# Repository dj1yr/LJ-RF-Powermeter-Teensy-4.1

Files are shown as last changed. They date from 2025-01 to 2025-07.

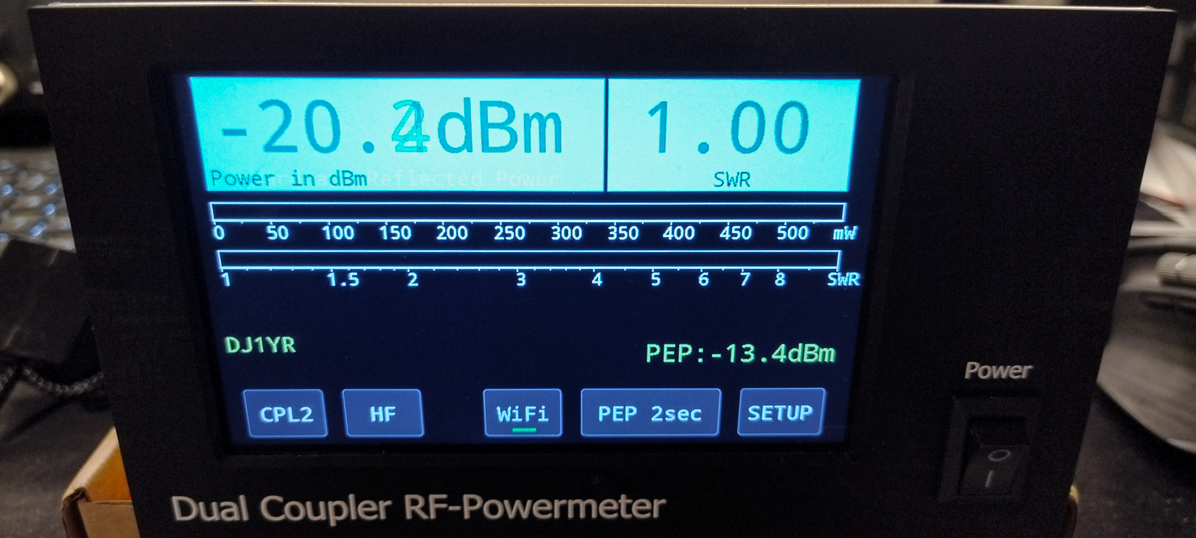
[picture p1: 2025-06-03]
IMG_20250603_050342225.jpg

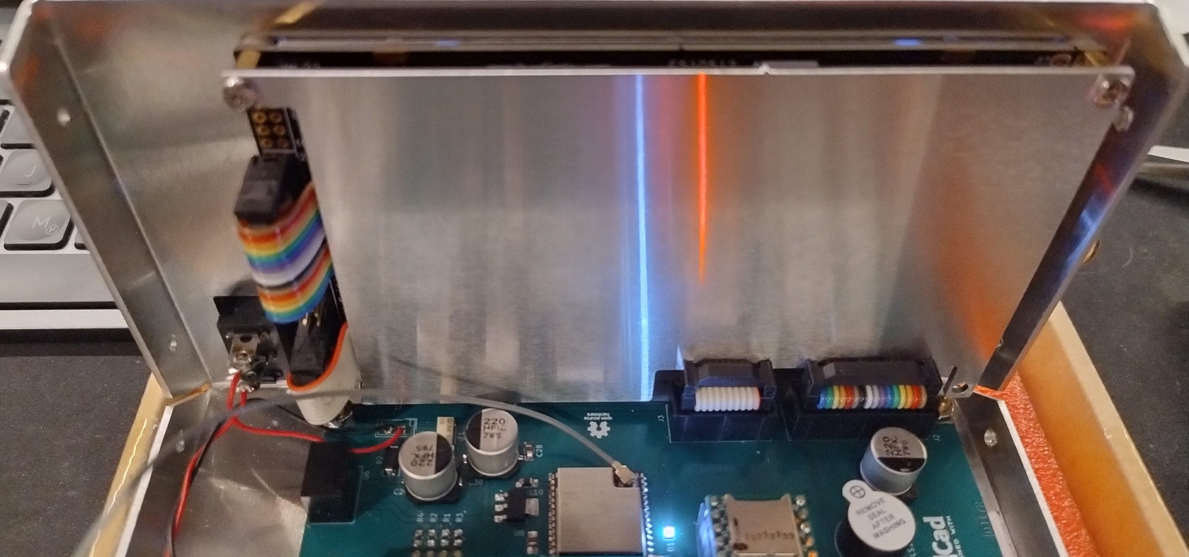
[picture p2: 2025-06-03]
IMG_20250603_050323348_HDR.jpg

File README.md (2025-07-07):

Here is a collection of files for the RF Powermeter with Teensy 4.0/4.1.
Since I could not find any source files for the PCB, I designed two boards based on Robert Entwistle (WA2T) and the really impressive software by Johan G. Holstein (PD0LEW).
The Rev3n is based on a main board on which different RF boards can be plugged to find the best solution for each application.

I try to create a complete folder with all files here, my board files are welcome to be used and improved.

The board was designed with Kicad and the enclosure parts are designed with Inventor.

73' René

**Revisions:**

REV3.6:

-Connection J2 pin14 to 3.3V(L13 + C3 must be populated for the new 7" display) 

-LAN and User I/O Header removed
-SMA connection added to User IO 6 if frequency measurement is added

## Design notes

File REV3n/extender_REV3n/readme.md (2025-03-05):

I have designed another RF extender board with HMC849 as RF switch, first measurements looked very good. The plan is to design an RF board up to 23cm, which then has 3 coupler inputs. Some adjustments have to be made to the software, so for the time being a version with two coupler inputs and AD8307.
The question has been asked why I am not using PE4259 as in the original design.
It is very difficult to get original working PE4259, I had ordered many from ebay, Ali etc, all were fakes.
Then I found the test boards with HMC 349/849, you can easily test them and make sure they work.
Since I have a hot air soldering station, it was very easy to take these tested ICs and place them on my board.
I also tried soldering them on with a soldering iron, which also worked, and I added a 2mm VIA to the ground plane under the HMC.

-In the REV3.6 the 74HC04 was removed, this was only found in the REV3.5.
-Operating the HMC with 5V did not bring any significant improvement.

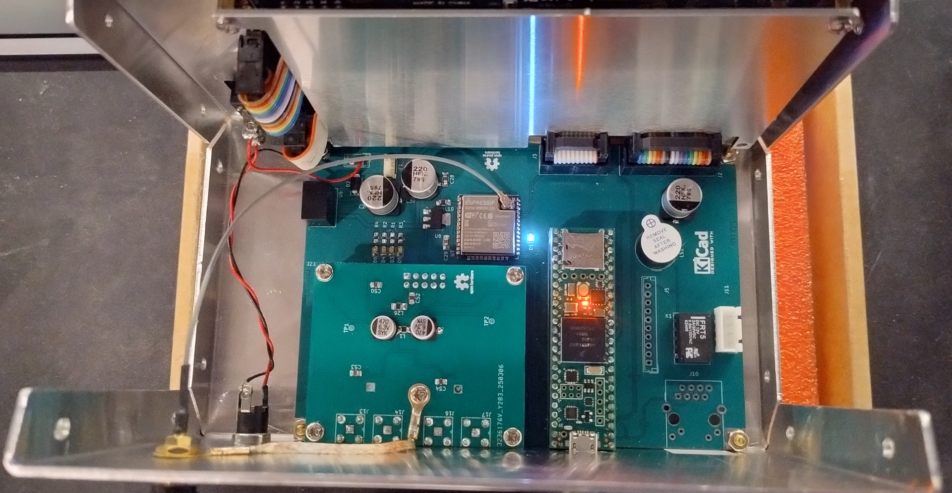
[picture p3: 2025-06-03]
IMG_20250603_050301073_HDR.jpg

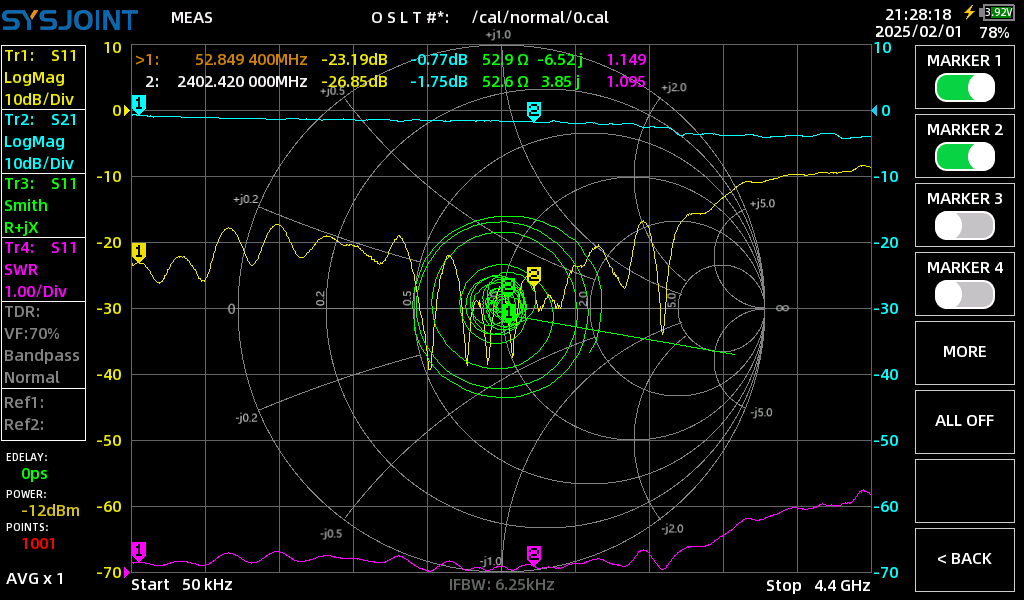
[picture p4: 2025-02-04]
REV3n/extender_REV3n/extender HMC/HMC849_S21_S11_50khzto4Ghz.png

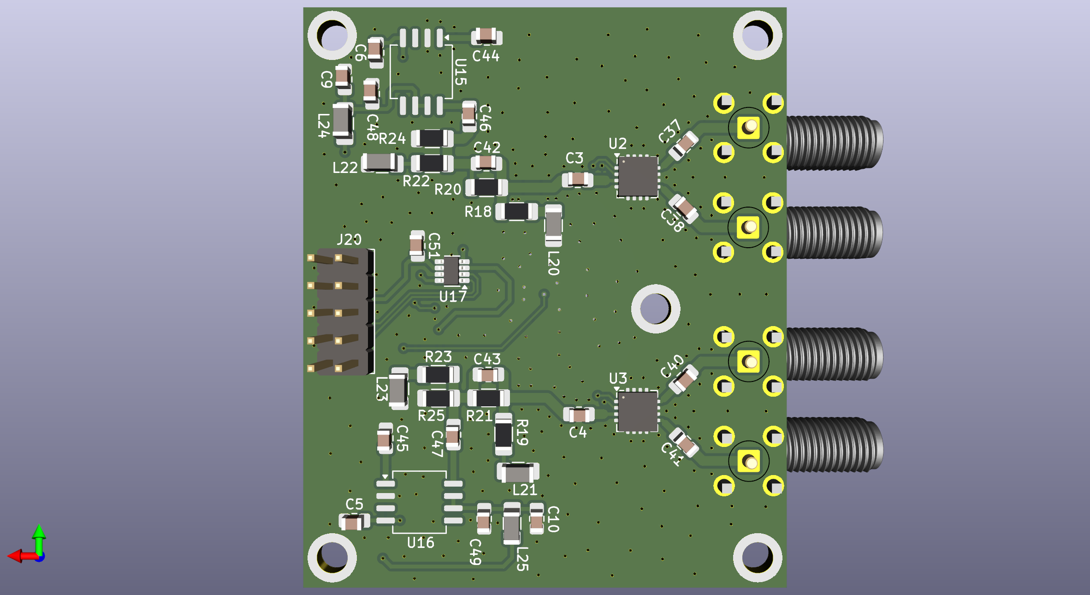
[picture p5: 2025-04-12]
REV3n/extender_REV3n/extender HMC/PowerMeter_REV37_2in_HMC_extender-bottom.png

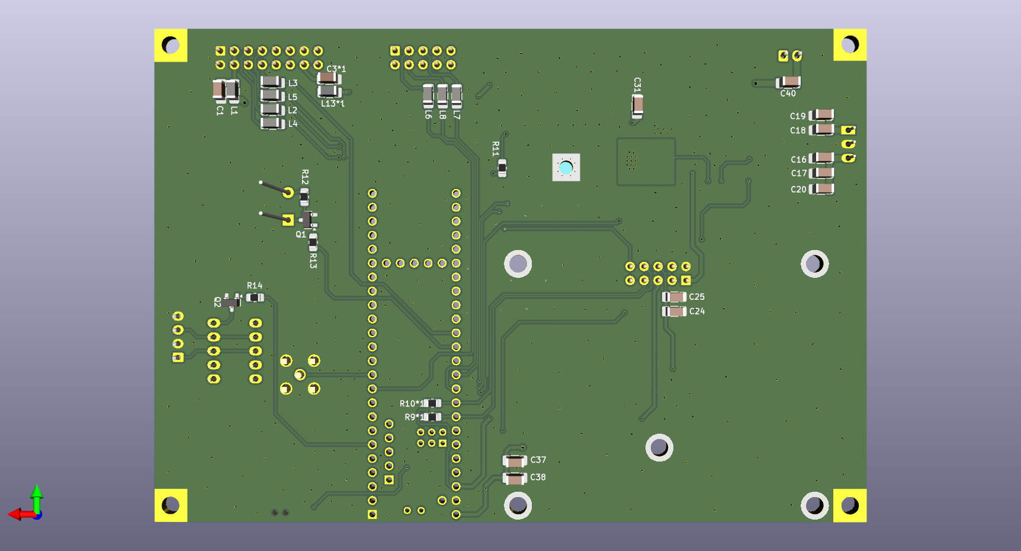
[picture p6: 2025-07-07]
REV3n/mainboard_REV3n/PowerMeter_REV36_bottom.png

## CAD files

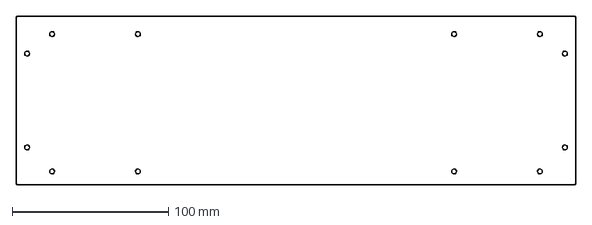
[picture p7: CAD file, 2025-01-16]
Case/Case 5"/Deckel.dxf
358.6 x 108.0 mm

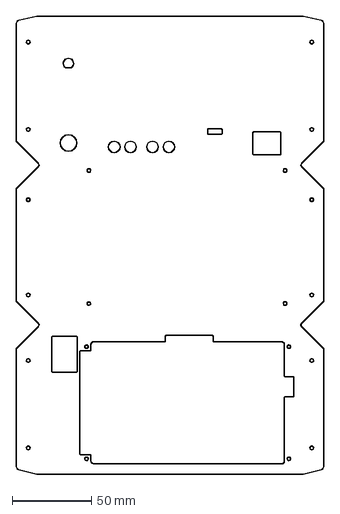
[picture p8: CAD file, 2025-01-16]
Case/Case 5"/Unterteil.dxf
193.6 x 288.6 mm

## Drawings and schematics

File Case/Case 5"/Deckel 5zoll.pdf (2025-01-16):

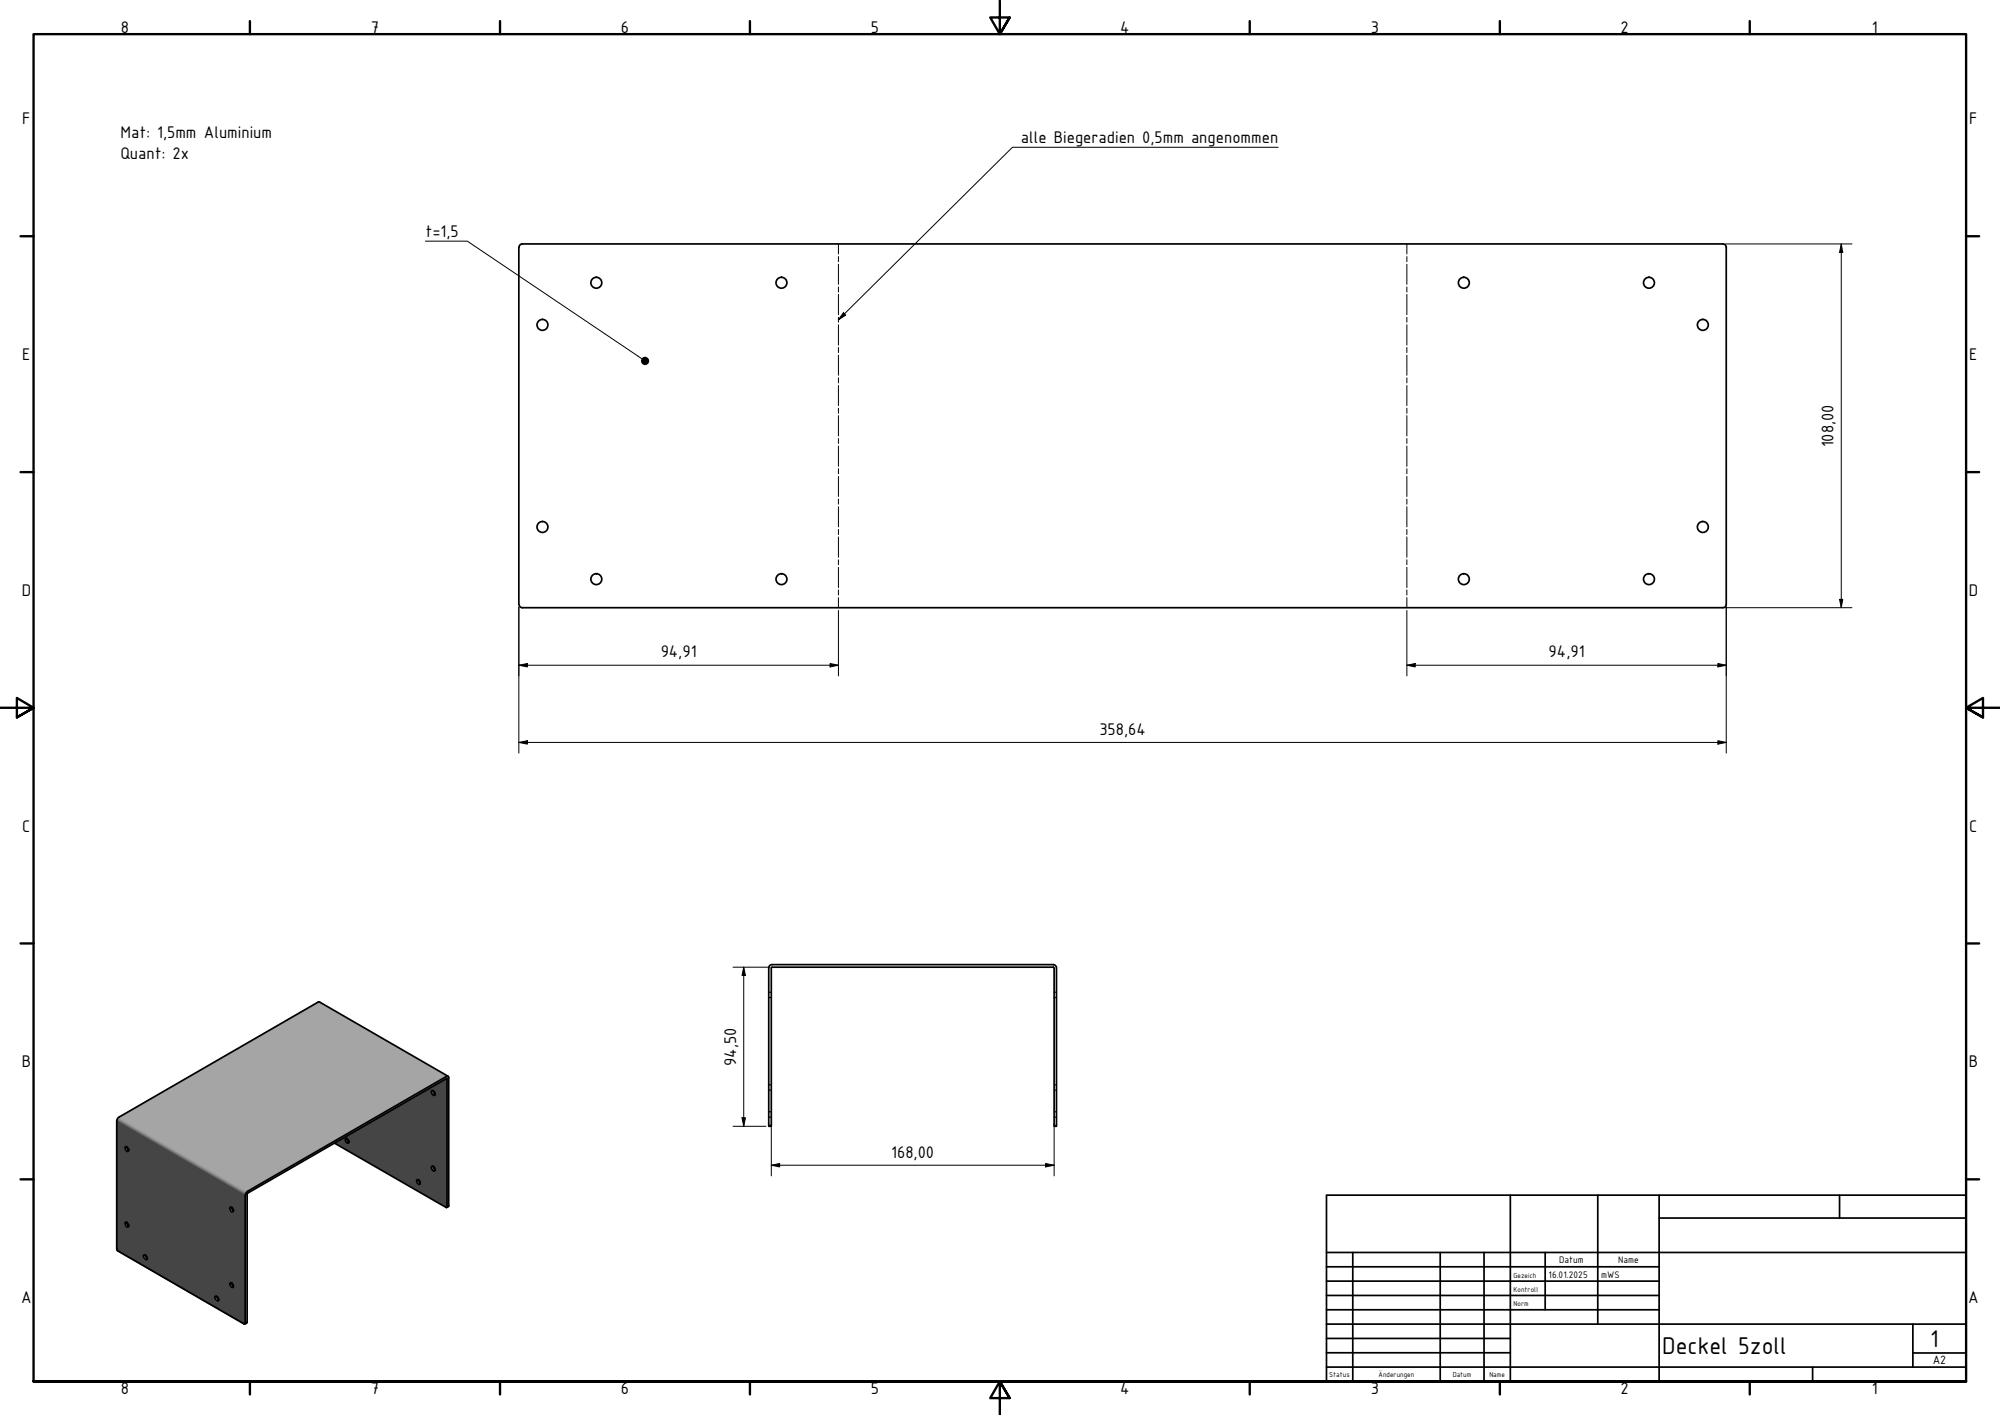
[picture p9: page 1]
Deckel 5zoll; Mat: 1,5mm Aluminium Quant: 2x

alle Biegeradien 0,5mm angenommen

Datum | Name

Gezeich | 16.01.2025 | mWS

Kontroll

Norm

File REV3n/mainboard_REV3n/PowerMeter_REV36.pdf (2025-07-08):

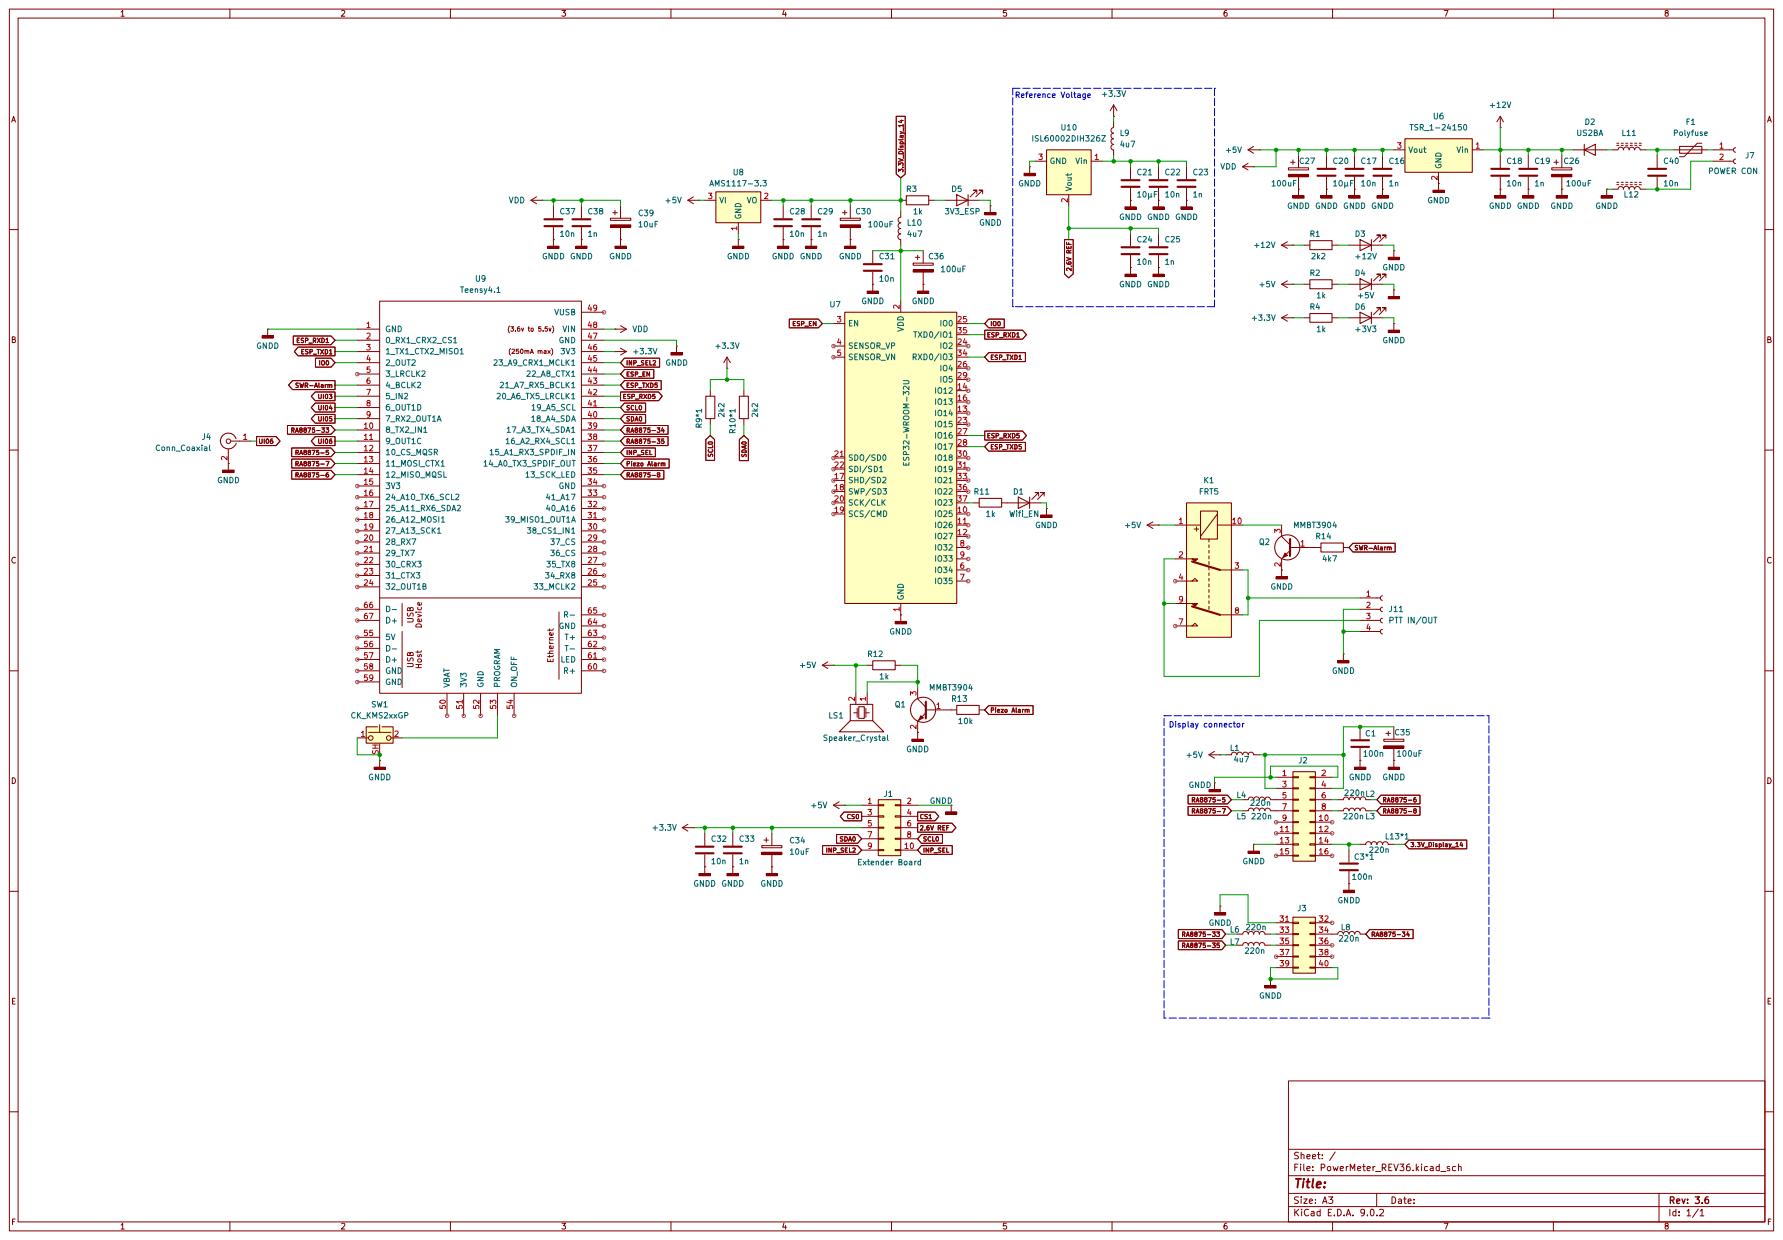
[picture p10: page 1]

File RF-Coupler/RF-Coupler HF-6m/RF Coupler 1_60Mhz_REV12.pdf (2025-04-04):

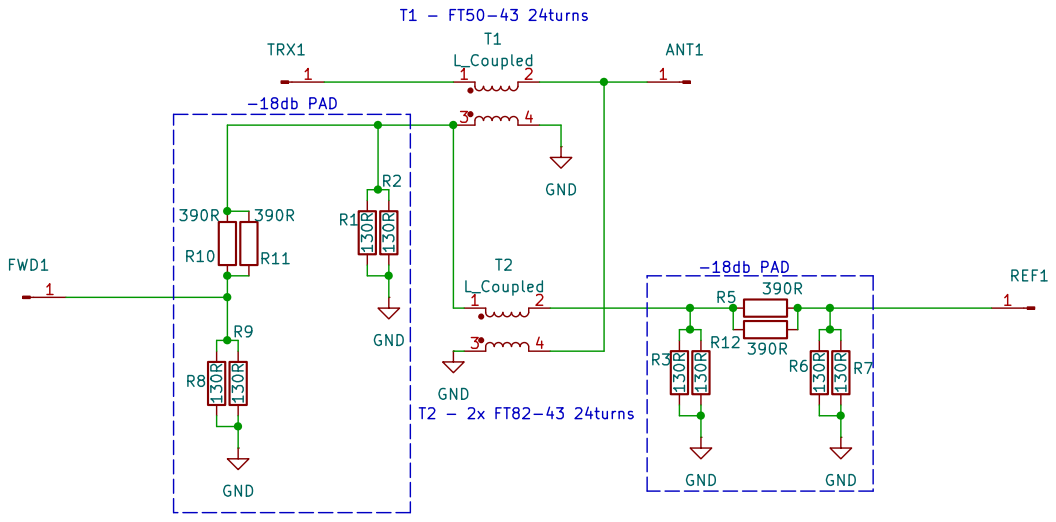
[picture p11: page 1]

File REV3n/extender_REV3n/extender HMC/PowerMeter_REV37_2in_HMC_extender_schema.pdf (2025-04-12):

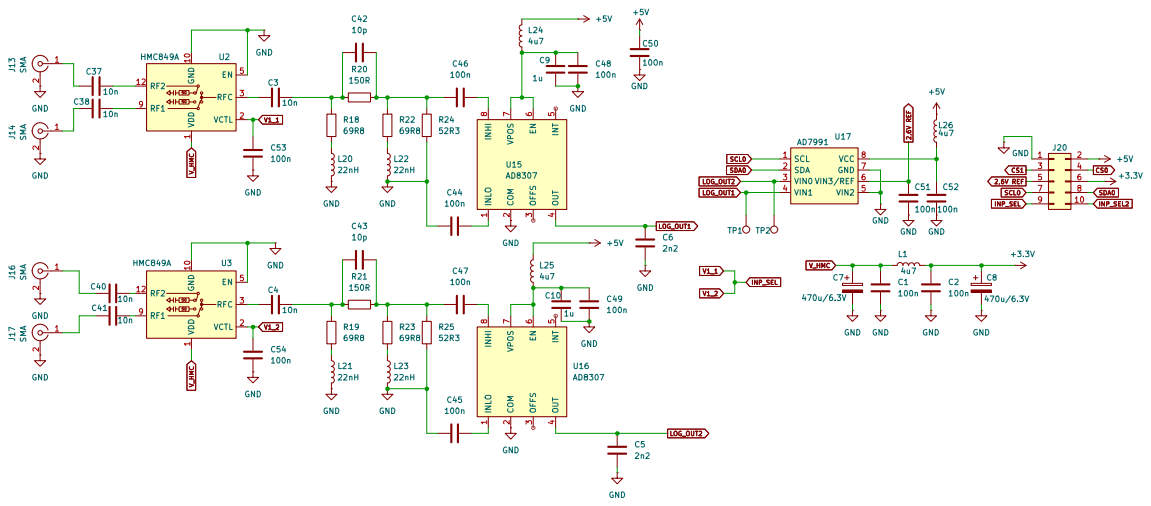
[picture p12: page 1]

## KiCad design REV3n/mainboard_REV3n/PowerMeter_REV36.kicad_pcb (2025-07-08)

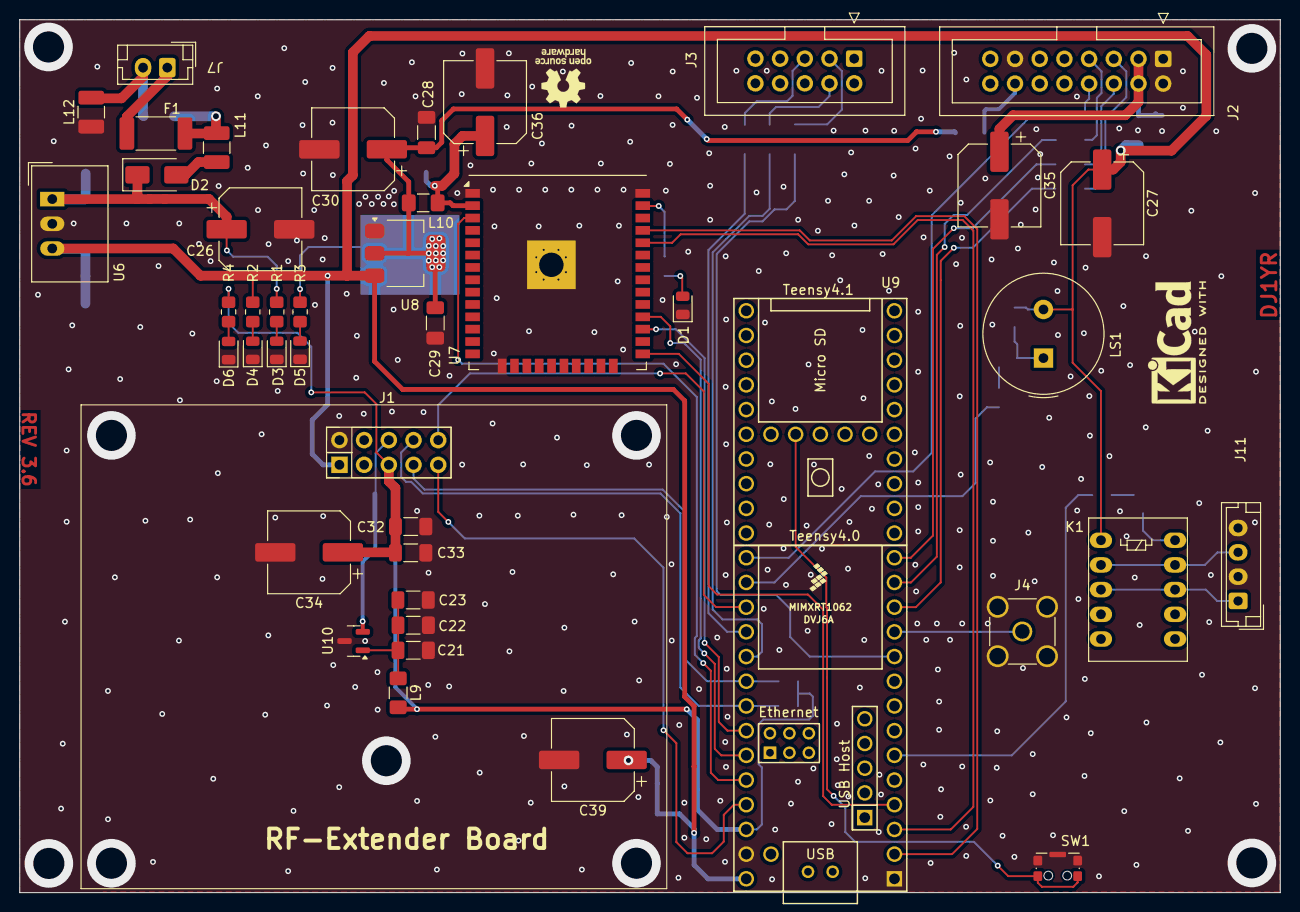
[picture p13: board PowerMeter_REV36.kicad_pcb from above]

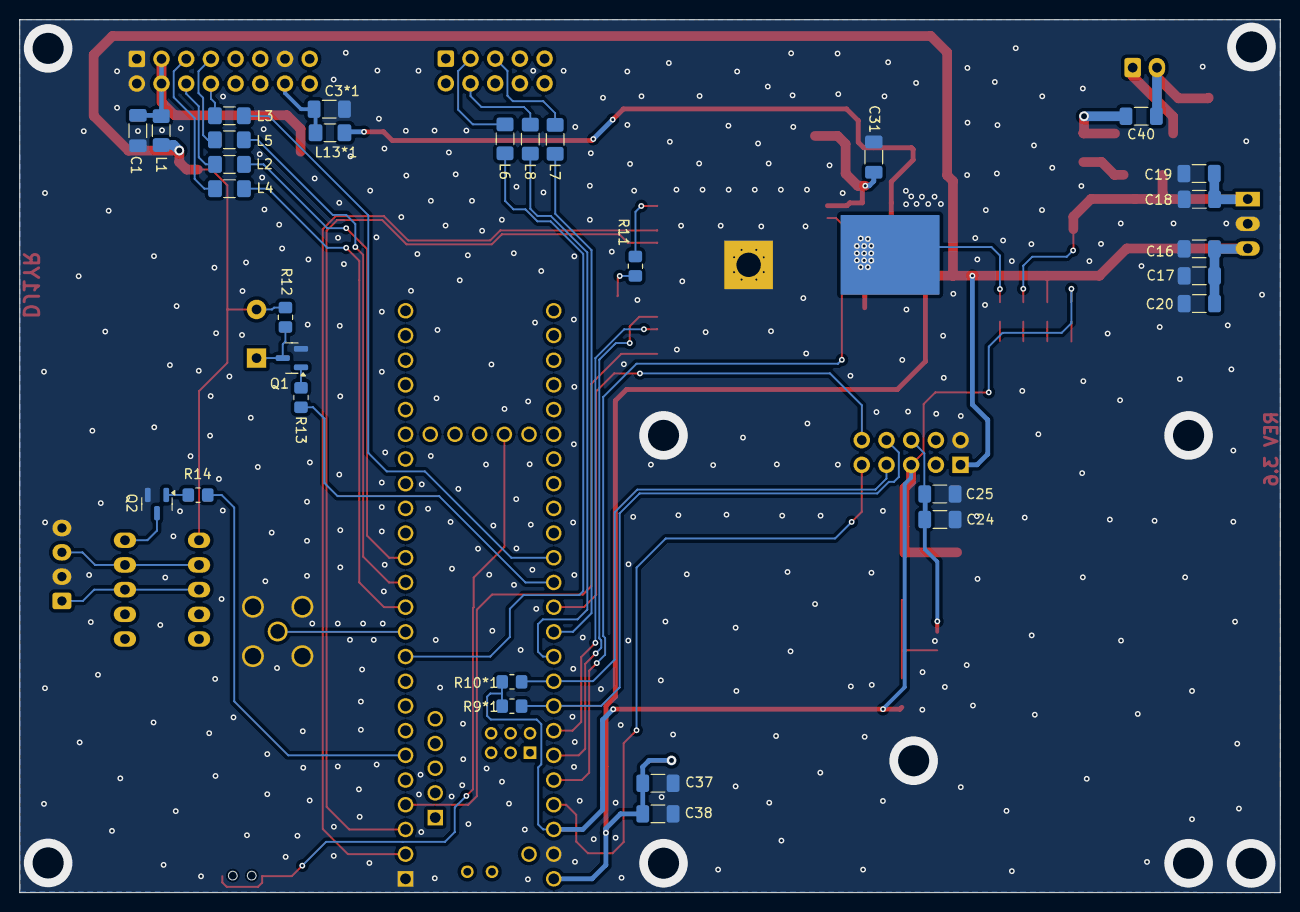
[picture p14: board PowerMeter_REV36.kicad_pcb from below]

Board: 2 copper layers, 129.6 x 89.8 mm, 73 parts (30 on the bottom side), 51 nets.

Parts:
C1, C3*1: 100n; C_1206_3216Metric_Pad1.33x1.80mm_HandSolder
C16, C19, C23, C25, C29, C33, C38: 1n; C_1206_3216Metric_Pad1.33x1.80mm_HandSolder
C17, C18, C22, C24, C28, C31, C32, C37, C40: 10n; C_1206_3216Metric_Pad1.33x1.80mm_HandSolder
C20, C21: 10µF; C_1206_3216Metric_Pad1.33x1.80mm_HandSolder
C26, C27, C30, C35, C36, C39: 100uF; CP_Elec_8x11.9
C34: 10uF; CP_Elec_8x11.9
D1: Wifi_EN; LED_0805_2012Metric
D2: US2BA; D_SMA
D3: +12V; LED_0805_2012Metric
D4: +5V; LED_0805_2012Metric
D5: 3V3_ESP; LED_0805_2012Metric
D6: +3V3; LED_0805_2012Metric
F1: Polyfuse; Fuse_2512_6332Metric_Pad1.52x3.35mm_HandSolder
J1: Extender Board; PinHeader_2x05_P2.54mm_Vertical
J2: Conn_02x08_Odd_Even; IDC-Header_2x08_P2.54mm_Vertical
J3: Conn_02x05_Odd_Even; IDC-Header_2x05_P2.54mm_Vertical
J4: Conn_Coaxial; SMA_Amphenol_132134-11_Vertical
J7: POWER CON; JST_EH_B2B-EH-A_1x02_P2.50mm_Vertical
J11: PTT IN/OUT; JST_EH_B4B-EH-A_1x04_P2.50mm_Vertical
K1: FRT5; Relay_DPDT_FRT5
L1, L9, L10: 4u7; L_1206_3216Metric_Pad1.42x1.75mm_HandSolder
L2, L3, L4, L5, L6, L7, L8, L13*1: 220n; L_1206_3216Metric_Pad1.42x1.75mm_HandSolder
L11, L12: L_Ferrite; L_1210_3225Metric_Pad1.42x2.65mm_HandSolder
LS1: Speaker_Crystal; Buzzer_TDK_PS1240P02BT_D12.2mm_H6.5mm
Q1, Q2: MMBT3904; SOT-23
R1, R9*1, R10*1: 2k2; R_0805_2012Metric_Pad1.20x1.40mm_HandSolder
R2, R3, R4, R11, R12: 1k; R_0805_2012Metric_Pad1.20x1.40mm_HandSolder
R13: 10k; R_0805_2012Metric_Pad1.20x1.40mm_HandSolder
R14: 4k7; R_0805_2012Metric_Pad1.20x1.40mm_HandSolder
SW1: CK_KMS2xxGP; SW_SPST_CK_KMS2xxGP
U6: TSR_1-24150; Converter_DCDC_TRACO_TSR-1_THT
U7: ESP32-WROOM-32U; ESP32-WROOM-32
U8: AMS1117-3.3; SOT-223-3_TabPin2
U9: Teensy4.1; Teensy41
U10: ISL60002DIH326Z; SOT-23

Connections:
2,6V REF: C24.2, C25.2, J1.6, U10.2 (Vout)
3.3V_Display_14: C28.2, C29.2, C30.1, L10.2, L13*1.2, R3.2, U8.2 (VO)
+3.3V: C32.2, C33.2, C34.1, J1.5, L9.2, R4.2, R9*1.1, R10*1.1, U9.46 (3V3)
+5V: C16.2, C17.2, C20.2, C27.1, C37.2, C38.2, C39.1, J1.1, K1.1, L1.2, LS1.2, R2.2, R12.2, U6.3 (Vout), U8.3 (VI), U9.48 (VIN)
+12V: C18.2, C19.2, C26.1, D2.1 (K), R1.2, U6.1 (Vin)
ESP_EN: U7.3 (EN), U9.44 (22_A8_CTX1)
ESP_RXD1: U7.35 (TXD0/IO1), U9.2 (0_RX1_CRX2_CS1)
ESP_RXD5: U7.27 (IO16), U9.42 (20_A6_TX5_LRCLK1)
ESP_TXD1: U7.34 (RXD0/IO3), U9.3 (1_TX1_CTX2_MISO1)
ESP_TXD5: U7.28 (IO17), U9.43 (21_A7_RX5_BCLK1)
GNDD: C1.1, C3*1.1, C16.1, C17.1, C18.1, C19.1, C20.1, C21.1, C22.1, C23.1, C24.1, C25.1, C26.2, C27.2, C28.1, C29.1, C30.2, C31.1, C32.1, C33.1, C34.2, C35.2, C36.2, C37.1, C38.1, C39.2, D1.1 (K), D3.1 (K), D4.1 (K), D5.1 (K), D6.1 (K), J1.2, J2.1, J2.2, J2.13, J4.2 (Ext), J11.2, J11.4, L12.1, Q1.2 (E), Q2.2 (E), SW1.1, SW1.SH (B), U6.2 (GND), U7.1 (GND), U7.15 (GND), U7.38 (GND), U7.39 (GND), U8.1 (GND), U9.1 (GND), U9.47 (GND), U10.3 (GND)
INP_SEL: J1.10, U9.37 (15_A1_RX3_SPDIF_IN)
INP_SEL2: J1.9, U9.45 (23_A9_CRX1_MCLK1)
IO0: U7.25 (IO0), U9.4 (2_OUT2)
unnamed: C40.2, F1.2, L11.2
unnamed: D1.2 (A), R11.1
unnamed: D2.2 (A), L11.1
unnamed: D3.2 (A), R1.1
unnamed: D4.2 (A), R2.1
unnamed: D5.2 (A), R3.1
unnamed: D6.2 (A), R4.1
unnamed: C1.2, C35.1, J2.3, J2.4, L1.1
unnamed: J2.5, L4.1
unnamed: J2.6, L2.1
unnamed: J2.7, L5.1
unnamed: J2.8, L3.1
unnamed: C3*1.2, J2.14, L13*1.1
unnamed: F1.1, J7.1
unnamed: C40.1, J7.2, L12.2
unnamed: J11.1, K1.3, K1.8
unnamed: J11.3, K1.2, K1.9
unnamed: Q1.1 (B), R13.2
unnamed: LS1.1, Q1.3 (C), R12.1
unnamed: Q2.1 (B), R14.2
unnamed: K1.10, Q2.3 (C)
unnamed: R11.2, U7.37 (IO23)
unnamed: C31.2, C36.1, L10.1, U7.2 (VDD)
unnamed: SW1.2, U9.53 (PROGRAM)
unnamed: C21.2, C22.2, C23.2, L9.1, U10.1 (Vin)
Piezo Alarm: R13.1, U9.36 (14_A0_TX3_SPDIF_OUT)
RA8875-5: L4.2, U9.12 (10_CS_MQSR)
RA8875-6: L2.2, U9.14 (12_MISO_MQSL)
RA8875-7: L5.2, U9.13 (11_MOSI_CTX1)
RA8875-8: L3.2, U9.35 (13_SCK_LED)
RA8875-33: L6.2, U9.10 (8_TX2_IN1)
RA8875-34: L8.2, U9.39 (17_A3_TX4_SDA1)
RA8875-35: L7.2, U9.38 (16_A2_RX4_SCL1)
SCL0: J1.8, R9*1.2, U9.41 (19_A5_SCL)
SDA0: J1.7, R10*1.2, U9.40 (18_A4_SDA)
SWR-Alarm: R14.1, U9.6 (4_BCLK2)
UI06: J4.1 (In), U9.11 (9_OUT1C)

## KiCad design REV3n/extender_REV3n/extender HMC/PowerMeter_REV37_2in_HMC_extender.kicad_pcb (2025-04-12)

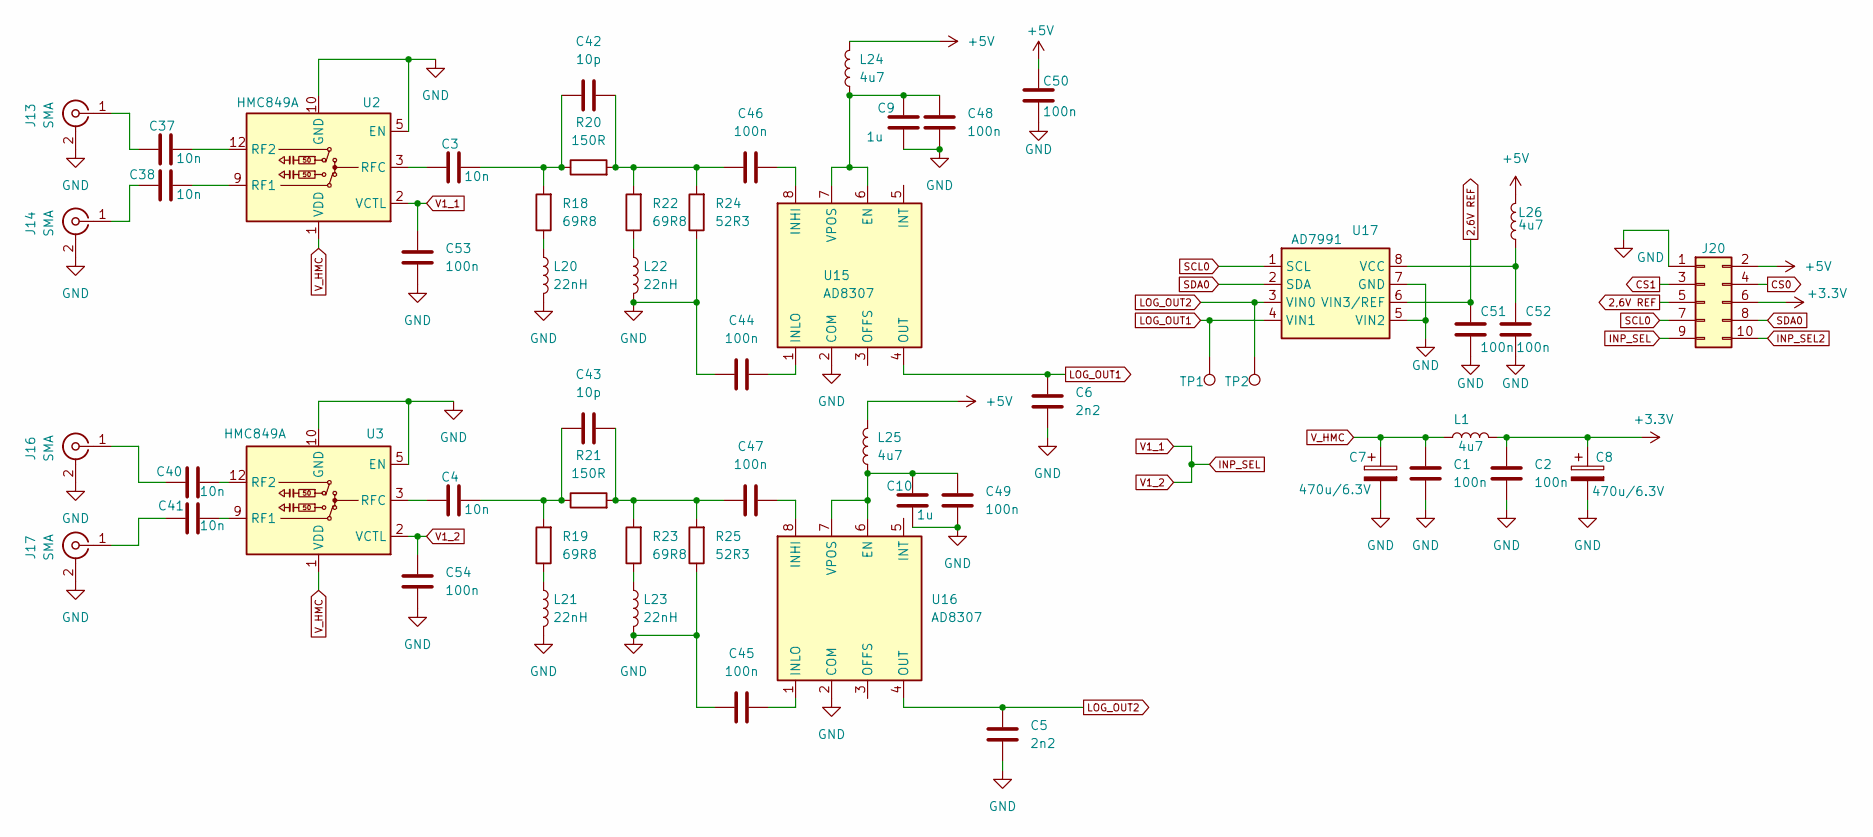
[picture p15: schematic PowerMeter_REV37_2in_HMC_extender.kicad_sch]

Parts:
C1, C2, C44, C45, C46, C47, C48, C49, C50, C51, C52, C53, C54: 100n; C_0805_2012Metric_Pad1.18x1.45mm_HandSolder
C3, C4, C37, C38, C40, C41: 10n; C_0805_2012Metric_Pad1.18x1.45mm_HandSolder
C5, C6: 2n2; C_0805_2012Metric_Pad1.18x1.45mm_HandSolder
C7, C8: 470u/6.3V; CP_Elec_6.3x5.4
C9, C10: 1u; C_0805_2012Metric_Pad1.18x1.45mm_HandSolder
C42, C43: 10p; C_0805_2012Metric_Pad1.18x1.45mm_HandSolder
J13, J14, J16, J17: SMA; SMA_BAT_Wireless_BWSMA-KWE-Z001
J20: Conn_02x05_Odd_Even; PinHeader_2x05_P2.54mm_Vertical
L1, L24, L25, L26: 4u7; L_1206_3216Metric_Pad1.42x1.75mm_HandSolder
L20, L21, L22, L23: 22nH; L_1206_3216Metric_Pad1.42x1.75mm_HandSolder
R18, R19, R22, R23: 69R8; R_1206_3216Metric_Pad1.30x1.75mm_HandSolder
R20, R21: 150R; R_1206_3216Metric_Pad1.30x1.75mm_HandSolder
R24, R25: 52R3; R_1206_3216Metric_Pad1.30x1.75mm_HandSolder
TP1, TP2: TestPoint; TestPoint_Pad_D1.0mm
U2, U3: HMC849A; LFCSP-16-1EP_4x4mm_P0.65mm_EP2.4x2.4mm
U15, U16: AD8307; SO-8_5.3x6.2mm_P1.27mm
U17: AD7991; TSOT-23-8

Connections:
2,6V REF: C51.2, J20.5, U17.6 (VIN3/REF)
+3.3V: C2.2, C8.1, J20.6, L1.1
+5V: C50.2, J20.2, L24.2, L25.2, L26.2
CS0: J20.4
CS1: J20.3
GND: C1.1, C2.1, C5.1, C6.1, C7.2, C8.2, C9.1, C10.1, C44.1, C45.1, C48.1, C49.1, C50.1, C51.1, C52.1, C53.1, C54.1, J13.2 (Ext), J14.2 (Ext), J16.2 (Ext), J17.2 (Ext), J20.1, L20.2, L21.2, L22.2, L23.2, R24.1, R25.1, U2.4 (GND), U2.5 (EN), U2.6 (GND), U2.7 (GND), U2.8 (GND), U2.10 (GND), U2.11 (GND), U2.13 (GND), U2.14 (GND), U2.15 (GND), U2.16 (GND), U2.17 (GND), U3.4 (GND), U3.5 (EN), U3.6 (GND), U3.7 (GND), U3.8 (GND), U3.10 (GND), U3.11 (GND), U3.13 (GND), U3.14 (GND), U3.15 (GND), U3.16 (GND), U3.17 (GND), U15.2 (COM), U16.2 (COM), U17.5 (VIN2), U17.7 (GND)
INP_SEL: C53.2, C54.2, J20.9, U2.2 (VCTL), U3.2 (VCTL)
INP_SEL2: J20.10
LOG_OUT1: C6.2, TP1.1, U15.4 (OUT), U17.4 (VIN1)
LOG_OUT2: C5.2, TP2.1, U16.4 (OUT), U17.3 (VIN0)
unnamed: C3.2, C42.1, R18.2, R20.1
unnamed: C4.2, C43.1, R19.2, R21.1
unnamed: C42.2, C46.1, R20.2, R22.2, R24.2
unnamed: C43.2, C47.1, R21.2, R23.2, R25.2
unnamed: C37.1, J13.1 (In)
unnamed: C38.1, J14.1 (In)
unnamed: C40.1, J16.1 (In)
unnamed: C41.1, J17.1 (In)
unnamed: L20.1, R18.1
unnamed: L21.1, R19.1
unnamed: L22.1, R22.1
unnamed: L23.1, R23.1
unnamed: C38.2, U2.9 (RF1)
unnamed: C37.2, U2.12 (RF2)
unnamed: C3.1, U2.3 (RFC)
unnamed: C41.2, U3.9 (RF1)
unnamed: C40.2, U3.12 (RF2)
unnamed: C4.1, U3.3 (RFC)
unnamed: C9.2, C48.2, L24.1, U15.6 (EN), U15.7 (VPOS)
unnamed: C46.2, U15.8 (INHI)
unnamed: C44.2, U15.1 (INLO)
unnamed: C10.2, C49.2, L25.1, U16.6 (EN), U16.7 (VPOS)
unnamed: C47.2, U16.8 (INHI)
unnamed: C45.2, U16.1 (INLO)
unnamed: C52.2, L26.1, U17.8 (VCC)
SCL0: J20.7, U17.1 (SCL)
SDA0: J20.8, U17.2 (SDA)
V_HMC: C1.2, C7.1, L1.2, U2.1 (VDD), U3.1 (VDD)

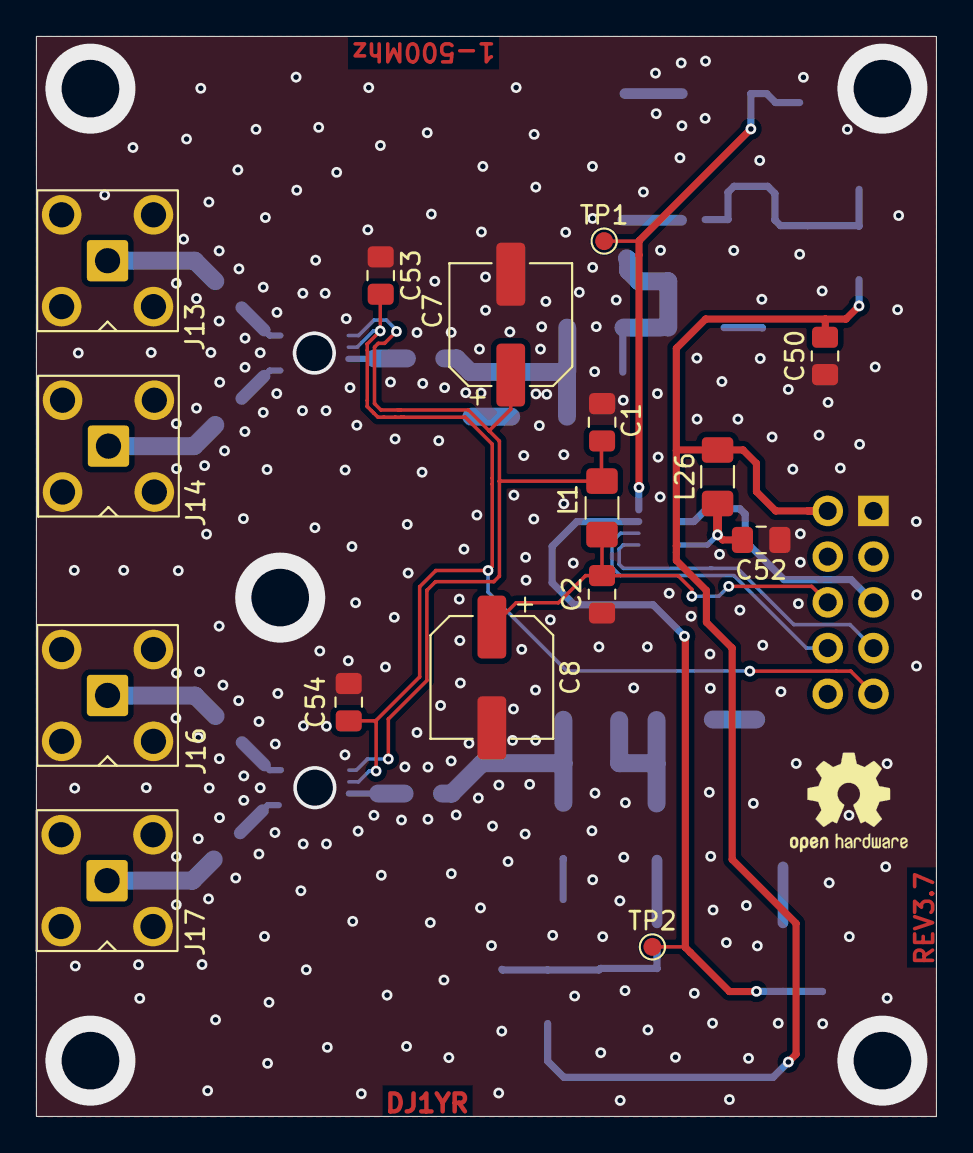
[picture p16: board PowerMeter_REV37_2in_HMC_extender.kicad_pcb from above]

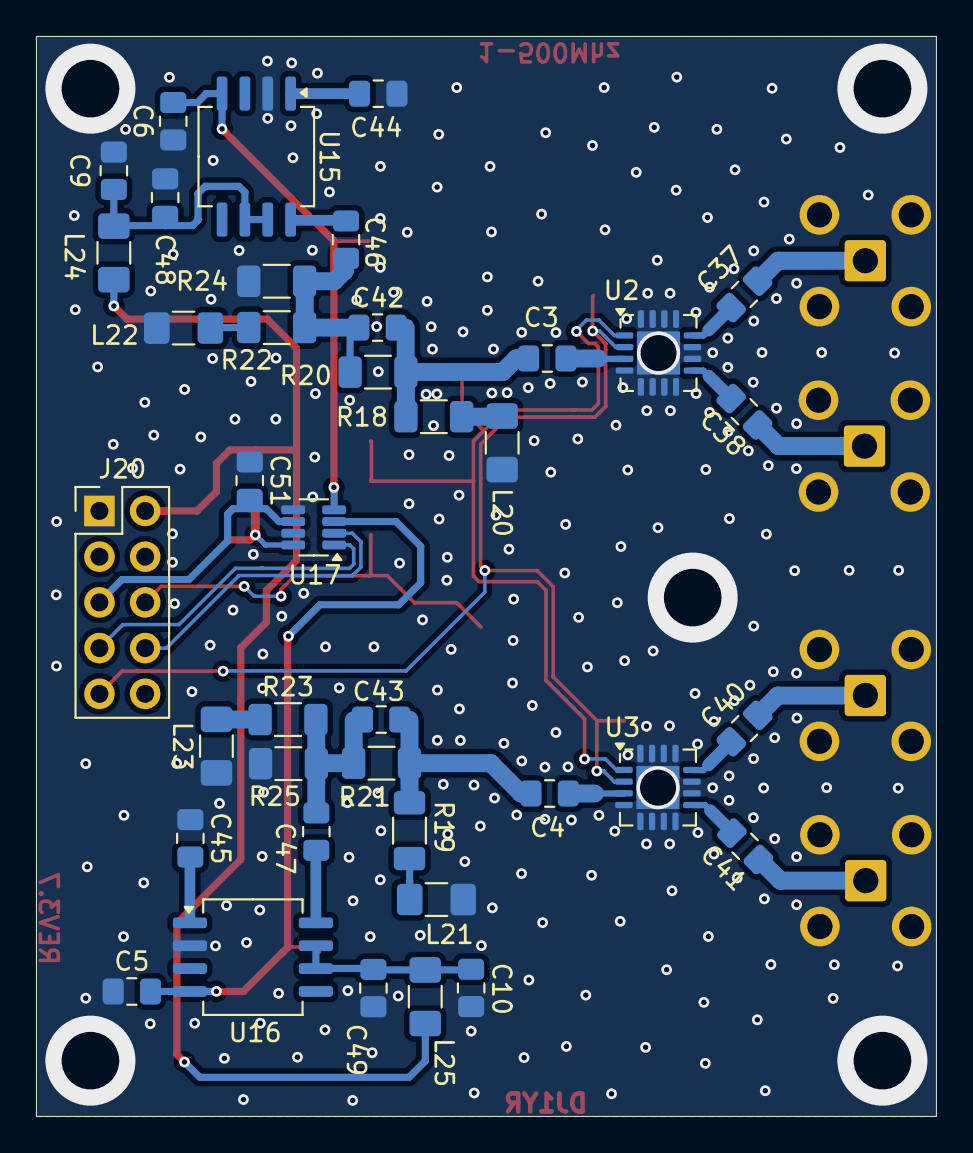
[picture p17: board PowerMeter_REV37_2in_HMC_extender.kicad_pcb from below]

Board: 2 copper layers, 50.0 x 60.0 mm, 55 parts (39 on the bottom side), 35 nets.

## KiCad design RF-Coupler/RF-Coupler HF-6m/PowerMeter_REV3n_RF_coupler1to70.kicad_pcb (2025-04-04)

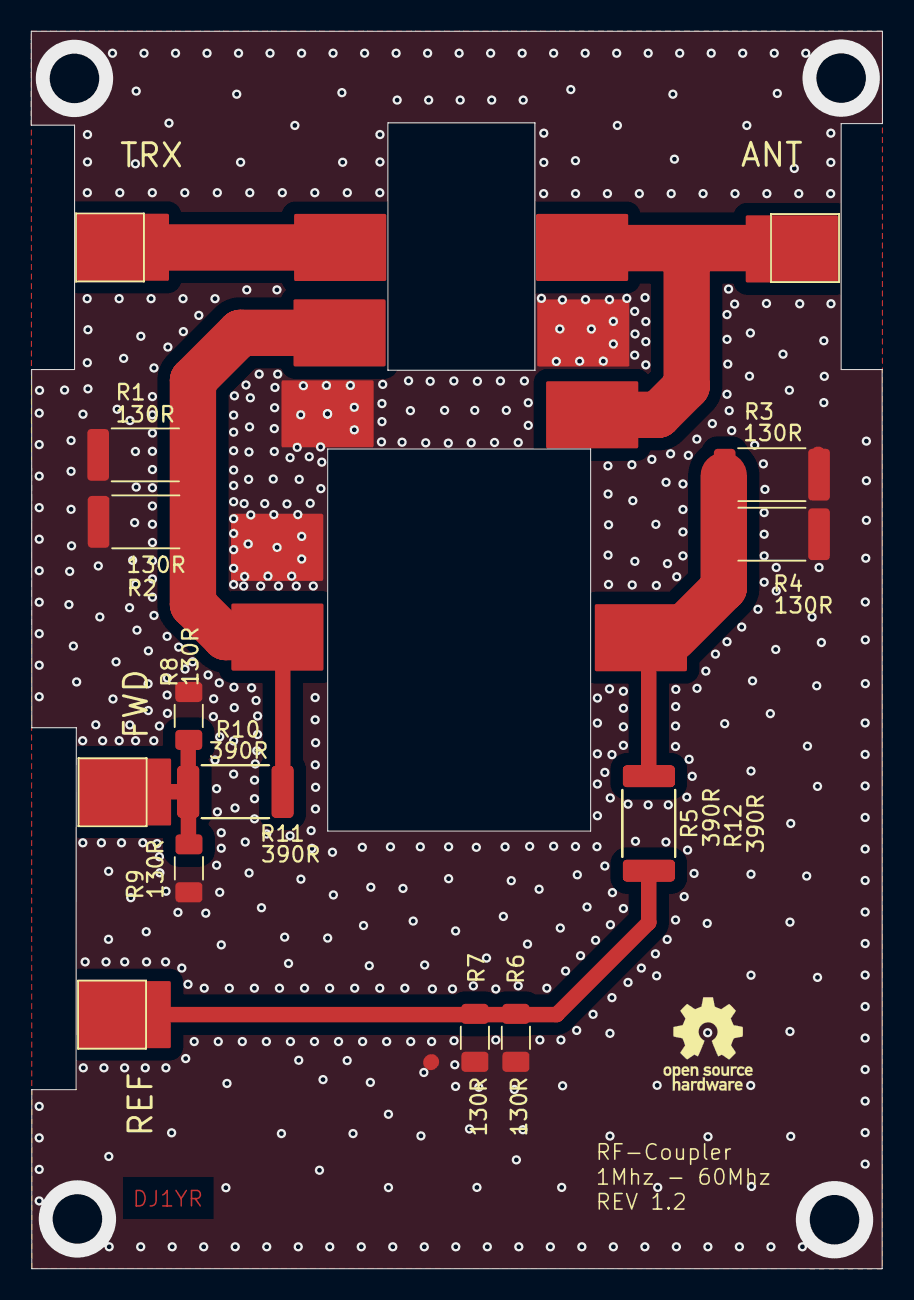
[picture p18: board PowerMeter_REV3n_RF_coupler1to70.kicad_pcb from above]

Board: 2 copper layers, 55.0 x 80.0 mm, 16 parts (0 on the bottom side), 5 nets.

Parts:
ANT1: TestPoint_Pad_4.0x4.0mm
FWD1: TestPoint_Pad_4.0x4.0mm
R1, R2, R3, R4: 130R; R_2512_6332Metric_Pad1.40x3.35mm_HandSolder
R5, R10, R11, R12: 390R; R_2512_6332Metric_Pad1.40x3.35mm_HandSolder
R6, R7, R8, R9: 130R; R_1206_3216Metric_Pad1.30x1.75mm_HandSolder
REF1: TestPoint_Pad_4.0x4.0mm
TRX1: TestPoint_Pad_4.0x4.0mm

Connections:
GND: R1.2, R2.2, R3.2, R4.2, R6.2, R7.2, R8.2, R9.2
unnamed: FWD1.1, R8.1, R9.1, R10.1, R11.1
unnamed: R1.1, R2.1, R10.2, R11.2
unnamed: R3.1, R4.1, R5.1, R12.1
unnamed: R5.2, R6.1, R7.1, R12.2, REF1.1
